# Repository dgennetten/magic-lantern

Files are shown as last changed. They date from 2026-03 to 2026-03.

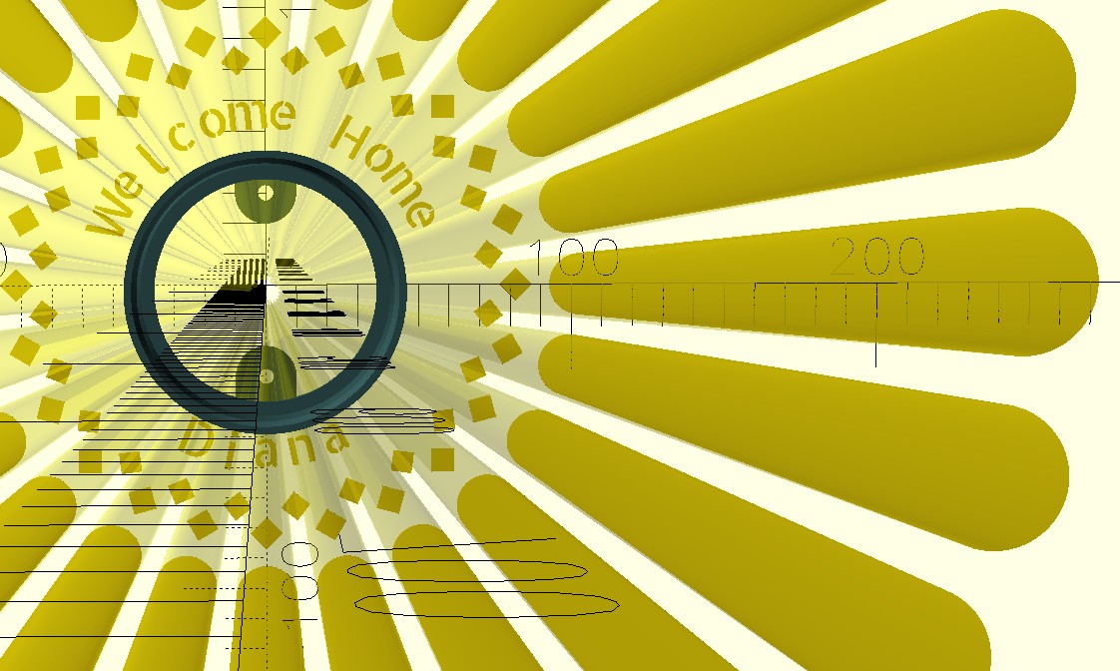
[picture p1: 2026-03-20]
Screenshot.jpg

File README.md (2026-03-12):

# Modular Projection Lantern Generator

A parametric OpenSCAD project for generating 3D-printable projection lanterns. This generator calculates the precise extrusion angles required to cast undistorted 2D patterns, shapes, and text onto a floor or surface from an elevated point light source.

## Features

* **Parametric LED Mounting:** Easily adjust variables to friction-fit any standard LED puck or light source.
* **Distortion-Corrected Projection:** Uses dynamic scaling to ensure patterns projecting further out maintain their intended visual proportions.
* **Multiple Render Modes:** * `PATTERNS`: Generates a fully customizable array of text, geometric shapes, and rays.
* `SVG`: Extrudes a custom vector file.
* `CAL`: Generates a 360-degree dot spiral to test projection accuracy at different radii.

* **Integrated Mounting Tabs:** Includes base tabs for securing the lantern to a ceiling or mounting bracket.

## Prerequisites

1. **OpenSCAD:** Download the latest version from [openscad.org](https://openscad.org/).
2. **Allerta Stencil Font:** The `PATTERNS` mode relies on this specific font to ensure physical text cutouts don't result in floating, unprintable islands.
* Download the `.ttf` file and place it in the same directory as `magicLantern.scad`.
* *Note: The script references the logical font name `"Allerta Stencil"`. Ensure it is properly installed on your system or placed in the local working directory.*

## Quick Start Guide

### 1. Configure Your Light Source

Open `magicLantern.scad` and locate the **Global Lantern Parameters** and **LED Mounting Parameters**. Measure your specific LED fixture and update the following:

* `light_height`: The distance from the bottom of the lantern to the actual light-emitting diode.
* `led_diameter`: The outer diameter of your physical LED fixture.
* `led_recess`: How far down inside the top cylinder the LED sits.
* `tolerance`: Adjust the clearance (default `0.25mm`) for a snug friction fit.

### 2. Choose Your Render Mode

Locate the `render_mode` variable and set it to one of the following strings:

* `"PATTERNS"`: Uses the built-in geometric and text modules.
* `"SVG"`: Extrudes a custom 2D vector file. (Make sure to update `svg_filename`, `svg_scale`, and the offset coordinates).
* `"CAL"`: Creates a shortened test lantern with a spiral of dots to verify your light height and projection focus.

### 3. Customize Patterns (Optional)

If using `PATTERNS` mode, scroll down to the `all_2d_patterns()` module. You can mix and match the included projection functions:

* `project_text(distance, msg, t_size, kerning_deg, phase_shift)`
* `project_polygon(distance, vertex, rot, n, duty, phase_shift)`
* `project_circles(distance, n, duty, phase_shift)`
* `project_rays(distance, bar_h, n, duty, phase_shift)`

*Tip: The `distance` parameter dictates how far down the lantern cylinder the pattern is cut. A smaller distance places the cutout higher up, closer to the light source, which projects further out onto the floor.*

### 4. Preview and Export

1. Press **F5** to preview your design.
2. *Important:* Ensure `show_light_rays = false;` before exporting, or the visualization rays will be added to your printable mesh!
3. Press **F6** to render the final geometry.
4. Go to **File > Export > Export as STL** (or 3MF).

## Slicing & Printing Recommendations

* **Resolution:** The script is set to `$fn = 120` for smooth cylindrical curves. A modern slicer like OrcaSlicer handles this high-resolution mesh perfectly and allows for excellent seam painting to hide the Z-seam along one of the mounting tabs.
* **Material:** Standard PLA is great for initial test prints or the `CAL` mode calibration ring. However, if your LED fixture generates noticeable heat during extended use, printing the final lantern in PETG is highly recommended to prevent warping.
* **Hardware:** Tested successfully on high-speed enclosed Core-XY machines (e.g., FlashForge AD5X).
* **Orientation:** Print the lantern vertically (LED cavity pointing up). No supports are required for the standard pattern cutouts.

---

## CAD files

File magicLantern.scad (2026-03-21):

// ==========================================
// MODULAR PROJECTION LANTERN GENERATOR
// ==========================================

// 1. Global Lantern Parameters
light_height = 90;
// Height of the LED point light source (Z axis origin)
cyl_radius = 40;
// Outer radius of the lantern cylinder
wall_thickness = 2;      // Thickness of the cylinder wall
font_name = "Allerta Stencil"; 
// Windows default Stencil font
use <AllertaStencil-Regular.ttf>;
$fn = 120;               // Smoothness of 3D curves

// 2. LED Mounting Parameters
led_diameter = 72.5;
// Outer diameter of physical LED light fixture
led_recess = 24;
// How far down inside the cylinder top the LED sits
tolerance = 0.25;
// Clearance for a snug friction fit

// 3. Visualization Toggle
show_light_rays = true;
// MUST BE FALSE for final F6 mesh export!

// ==========================================
// 4. RENDER MODE & SVG CONTROLS
// ==========================================
// Select: "PATTERNS", "SVG", or "CAL"
render_mode = "PATTERNS";
svg_filename = "my_pattern.svg"; 
svg_scale = 1.0;         
svg_x_offset = 0;        
svg_y_offset = 0;
// Pre-calculated physical arc widths for the ray cutouts
width_24 = (2 * PI * cyl_radius / 24) * 0.5;
width_12 = (2 * PI * cyl_radius / 12) * 0.5;
// REFACTORED: Calculates floor radius based on distance down from the LED
function get_floor_r(distance) = (light_height * cyl_radius) / distance;

// ==========================================
// 2D FLOOR PATTERN MODULES
// ==========================================
module project_text(distance, msg, t_size=8, kerning_deg=12, f_name=font_name, phase_shift=0, location="top") {
    floor_r = get_floor_r(distance);
    chars = len(msg);
    total_angle = (chars - 1) * kerning_deg;
    // Half-span so the midpoint between first and last glyph sits at noon (top) or 6 o'clock (bottom).
    start_angle = total_angle / 2;
    bottom = (location == "bottom");
    center_angle = bottom ? 180 : 0;
    // phase_shift=0: arc centered on center_angle. Nonzero: extra rotation in kerning_deg steps.
    angle_offset = kerning_deg * phase_shift;
    for (i = [0 : chars - 1]) {
        a = bottom
            ? (center_angle - start_angle + i * kerning_deg + angle_offset)
            : (center_angle + start_angle - i * kerning_deg + angle_offset);
        rotate(a)
            translate([0, floor_r])
                rotate(bottom ? 180 : 0)
                    text(msg[i], size=t_size, font=f_name, halign="center", valign="center");
    }
}

module project_rays(distance, bar_h, n, duty=0.5, phase_shift=0) {
    // A smaller distance is closer to the light source (higher up the cylinder)
    dist_top = distance - (bar_h / 2);
    dist_bottom = distance + (bar_h / 2);
    
    // The top of the ray projects further out onto the floor than the bottom
    r_outer = get_floor_r(dist_top);
    r_inner = get_floor_r(dist_bottom);
    
    angle_step = 360 / n;
    wedge_angle = angle_step * duty;
    angle_offset = angle_step * phase_shift;
    for (i = [0 : n - 1]) {
        rotate(i * angle_step + angle_offset)
            polygon([
                [ r_inner * tan(wedge_angle/2), r_inner ],
                [ r_outer * tan(wedge_angle/2), r_outer ],
                [-r_outer * tan(wedge_angle/2), r_outer ],
                [-r_inner * tan(wedge_angle/2), r_inner ]
            ]);
    }
}

module project_circles(distance, n, duty=0.5, phase_shift=0) {
    floor_r = get_floor_r(distance);
    angle_step = 360 / n;
    c_r = floor_r * sin((angle_step * duty) / 2);
    angle_offset = angle_step * phase_shift;
    for (i = [0 : n - 1]) {
        rotate(i * angle_step + angle_offset)
            translate([0, floor_r])
                circle(r = c_r);
    }
}

module project_polygon(distance, vertex, rot=0, n=24, duty=0.5, phase_shift=0) {
    floor_r = get_floor_r(distance);
    angle_step = 360 / n;
    p_r = floor_r * sin((angle_step * duty) / 2);
    angle_offset = angle_step * phase_shift;
    for (i = [0 : n - 1]) {
        rotate(i * angle_step + angle_offset)
            translate([0, floor_r])
                // +90 forces 1st vertex to 12 o'clock.
                // -rot applies clockwise offset.
                rotate(90 - rot)
                    circle(r = p_r, $fn = vertex);
    }
}

module project_cal_spiral(start_r=75, end_r=300, dots=37, dot_size=5) {
    // 37 dots guarantees exactly one dot every 10 degrees for a full 360 turn
    for (i = [0 : dots - 1]) {
        angle = i * (360 / (dots - 1));
        floor_r = start_r + i * ((end_r - start_r) / (dots - 1));
        rotate(angle)
            translate([0, floor_r])
                circle(d = dot_size);
    }
}

module all_2d_patterns() {
    if (render_mode == "PATTERNS") {
        // Distances recalculated from 130mm light_height to maintain exact visual placement
        project_text(distance = 65, msg = "WELCOME HOME", t_size = 12, kerning_deg = 12, location = "top");
        project_text(distance = 65, msg = "DIANA", t_size = 12, kerning_deg = 12, location = "bottom");
        // Diamonds (vertex=4, rot=0)
        project_polygon(distance = 44, vertex = 4, rot = 0, n = 20, duty = 0.5);
        // Diamonds (vertex=4, rot=0, phase_shift=.5)
        project_polygon(distance = 49, vertex = 4, rot = 0, n = 20, duty = 0.5, phase_shift = 0.5);
        project_circles(distance = 35, n = 20, duty = 0.75);
        project_rays(distance = 25, bar_h = width_24 * 4, n = 20, duty = 0.75);
        project_circles(distance = 14.5, n = 20, duty = 0.75);

    } else if (render_mode == "SVG") {
        translate([svg_x_offset, svg_y_offset])
            scale([svg_scale, svg_scale])
                import(svg_filename);
    } else if (render_mode == "CAL") {
        project_cal_spiral();
    } else {
        echo("ERROR: render_mode must be 'PATTERNS', 'SVG', or 'CAL'");
    }
}

// ==========================================
// 3D LANTERN COMPONENTS
// ==========================================
module lantern_body() {
    fit_radius = (led_diameter / 2) + tolerance;
    // Slight Z overlap between inner void and LED cavity avoids coplanar faces at light_height
    // (fixes phantom sheet in preview / bad STL facets).
    merge_eps = 0.05;
    
    total_height = light_height + led_recess;
    // Auto-shorten the cylinder by 50mm if doing a Calibration print
    cyl_bottom_z = (render_mode == "CAL") ? 50 : 0;

    // Scale math to avoid the tip singularity during extrusion
    extrude_h = light_height - 5;
    extrude_scale = (light_height - extrude_h) / light_height;

    union() {
        difference() {
            // 1. Solid Master Cylinder (Shortened for CAL mode)
            translate([0, 0, cyl_bottom_z])
                cylinder(h = total_height - cyl_bottom_z, r = cyl_radius);
            // 2. Main Inner Lantern Void (full height to LED plane — no inner lip)
            translate([0, 0, cyl_bottom_z - 0.1]) 
                cylinder(h = light_height - cyl_bottom_z + 0.1 + merge_eps, r = cyl_radius - wall_thickness);
            // 3. The LED Cavity (starts slightly below light_height to merge booleans with void)
            translate([0, 0, light_height - merge_eps])
                cylinder(h = led_recess + 0.1 + merge_eps, r = fit_radius);
            // 4. Chamfer for easy LED insertion
            translate([0, 0, total_height - 2])
                cylinder(h = 2.1, r1 = fit_radius, r2 = fit_radius + 1.5);
            // 5. Extrude the 2D patterns
            linear_extrude(height = extrude_h, scale = extrude_scale) {
                all_2d_patterns();
            }
        }
        
        // 6. Mounting Tabs (Flush with the bottom edge)
        tab_r = 10;
        hole_r = 2.5;
        tab_h = 3;
        
        // Moved the center inward by 10mm total from outer radius (y=30 instead of y=35)
        offset_y = 30;
        translate([0, 0, cyl_bottom_z]) {
            difference() {
                // Solid tabs, intersected with outer cylinder so the straight lines end cleanly
                intersection() {
                    union() {
                        // 12 o'clock U-shape
                        translate([0, offset_y, 0]) cylinder(h = tab_h, r = tab_r);
                        translate([-tab_r, offset_y, 0]) cube([tab_r * 2, cyl_radius - offset_y, tab_h]);
                        // 6 o'clock U-shape
                        translate([0, -offset_y, 0]) cylinder(h = tab_h, r = tab_r);
                        translate([-tab_r, -cyl_radius, 0]) cube([tab_r * 2, cyl_radius - offset_y, tab_h]);
                    }
                    cylinder(h = tab_h, r = cyl_radius);
                }
                // 5mm concentric screw holes
                translate([0, offset_y, -0.1]) cylinder(h = tab_h + 0.2, r = hole_r);
                translate([0, -offset_y, -0.1]) cylinder(h = tab_h + 0.2, r = hole_r);
            }
        }
    }
}
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

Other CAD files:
magicLanternJadeJulian.scad

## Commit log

2026-03-11 Initial commit: OpenSCAD magic lantern and SVG patterns
    Made-with: Cursor
    [magicLantern.scad]
2026-03-11 Update magicLantern.scad: Increased cylinder radius to 40mm for LED support, added calibration mode for rendering, and introduced a new spiral projection module. Adjusted lantern body dimensions for 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
    [magicLantern.scad]
2026-03-12 Refactor magicLantern.scad: Updated cylinder structure to include mounting tabs for improved stability, adjusted light ray visualization setting, and refined extrusion parameters for better design ac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
    [magicLantern.scad]
2026-03-12 Add README for Modular Projection Lantern Generator
    Added detailed project description, features, prerequisites, quick start guide, and printing recommendations.
2026-03-20 Enhance project_text module in magicLantern.scad to support text positioning with a new 'location' parameter. Updated example calls in all_2d_patterns to demonstrate top and bottom text projection.
    [magicLantern.scad]
2026-03-20 Refactor project_text module in magicLantern.scad to improve text positioning logic and update example calls. Adjusted angle calculations for better alignment of projected text. Updated Screenshot.jp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
    [magicLantern.scad]
2026-03-21 Jade & Julian's Bedroom
    [magicLanternJadeJulian.scad]
2026-03-21 ALL CAPS Stencils
    [magicLantern.scad]
